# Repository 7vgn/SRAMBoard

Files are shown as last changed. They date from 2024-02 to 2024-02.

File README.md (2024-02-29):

# SRAM Board evolved
## An Add-On for the ATmega644(A) Evaluation Board

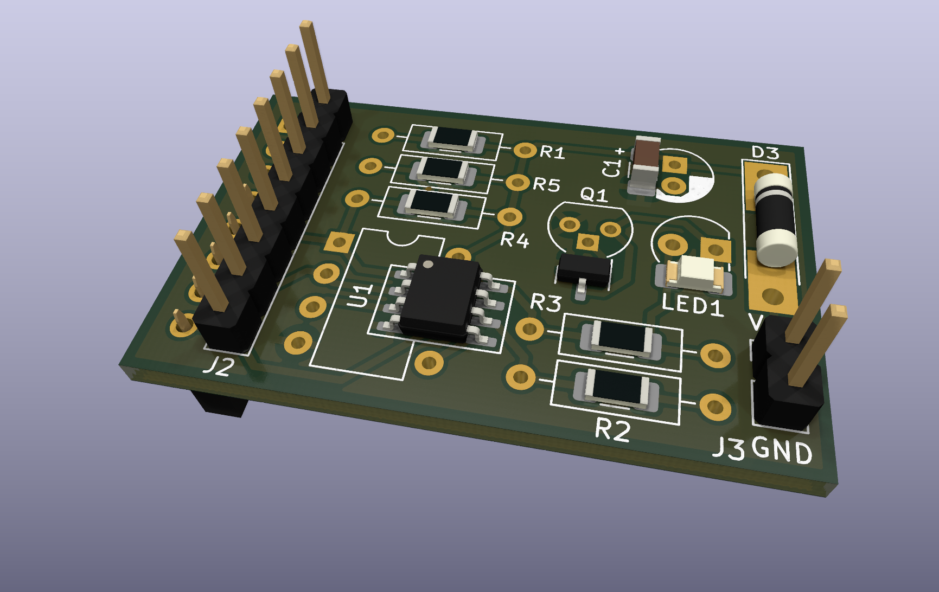
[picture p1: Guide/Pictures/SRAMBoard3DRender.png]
3D render of the add-on board


This is an add-on for the [EvaBoard evolved](https://github.com/7vgn/EvaBoard/) ATmega644(A) evaluation board. It is inspired by (and compatible with) the [add-on board](https://www.embedded.rwth-aachen.de/doku.php?id=lehre:atmegaevaboard) used in the lab course "Praktikum Systemprogrammierung" in the computer science curriculum at RWTH Aachen. It can be used both with the original evaluation board and its remake. 

This repository contains:

- A richly illustrated [Guide Book](Guide/SRAMBoardGuide.pdf) with everything you need to know to build and use the board
- A [KiCAD project](KiCAD/) with the [Schematic](KiCAD/Schematic.pdf) and a PCB layout, ready to be manufactured
- The [bill of materials](BOM/BOM.pdf)
- [Test code](Tests/) for testing and debugging the board

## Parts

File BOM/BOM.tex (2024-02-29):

\documentclass{article}
\usepackage[a4paper, landscape, margin=2.5cm]{geometry}
\usepackage{multirow}
\usepackage{longtable}
\usepackage{textgreek}
\usepackage{hyperref}

\setlength\parindent{0pt}

\begin{document}
\pagestyle{empty}
\section*{SRAM Board evolved -- Bill of Materials}
There is a through-hole and an SMD option for each component. You can mix and match. 
The table below lists the codes for ordering from \href{https://reichelt.de/}{Reichelt}. 
~\\

\begin{center}
\begin{tabular}{|l|l|l|l|l|}
\hline
\textbf{Reference}&\textbf{Part}&\textbf{Quantity}&\textbf{Reichelt\# (THT)}&\textbf{Reichelt\# (SMD)}\cr\hline
C1&Capacitor 100 \textmu F&1&TANTAL 100/6,3&X5R-G1206 100/6\cr\hline
D3&Diode 1N4004&1&1N 4004&1N 4004 SMD\cr\hline
J1&Pin Socket (female) 2.54mm&1&\multicolumn{2}{|l|}{MPE 094-1-008}\cr\hline
J2, J3&Pin Header (male) 2.54mm&1&\multicolumn{2}{|l|}{SL 1X36G 2,54}\cr\hline
LED1&LED (red)&1&LED 3MM RT&KBT KP-3216EC\cr\hline
Q1&NPN Transistor&1&BC 337-25&BC 817-25 SMD\cr\hline
R1, R5&Resistor 1k\textOmega&2&METALL 1,00K&SMD 1/4W 1,0K\cr\hline
R2, R4&Resistor 10k\textOmega&2&METALL 10,0K&SMD 1/4W 10K\cr\hline
R3&Resistor 470\textOmega&1&METALL 470&SMD 1/4W 470\cr\hline
\multirow{2}{*}{U1}&SRAM IC 23LC1024&1&\multicolumn{2}{|l|}{see Guide Book}\cr\cline{2-5}
&Socket&1&GS 8P&--\cr\hline
\end{tabular}
\end{center}

\end{document}

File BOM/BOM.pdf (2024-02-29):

## SRAM Board evolved – Bill of Materials

There is a through-hole and an SMD option for each component. You can mix and match. The table below lists the codes for ordering from Reichelt. (https://reichelt.de/)

Reference | Part | Quantity | Reichelt# (THT) | Reichelt# (SMD)
C1 | Capacitor 100 µF | 1 | TANTAL 100/6,3 | X5R-G1206 100/6
D3 | Diode 1N4004 | 1 | 1N 4004 | 1N 4004 SMD
J1 | Pin Socket (female) 2.54mm | 1 | MPE 094-1-008
J2, J3 | Pin Header (male) 2.54mm | 1 | SL 1X36G 2,54
LED1 | LED (red) | 1 | LED 3MM RT | KBT KP-3216EC
Q1 | NPN Transistor | 1 | BC 337-25 | BC 817-25 SMD
R1, R5 | Resistor 1kΩ | 2 | METALL 1,00K | SMD 1/4W 1,0K
R2, R4 | Resistor 10kΩ | 2 | METALL 10,0K | SMD 1/4W 10K
R3 | Resistor 470Ω | 1 | METALL 470 | SMD 1/4W 470
U1 | SRAM IC 23LC1024 | 1 | see Guide Book
| Socket | 1 | GS 8P | –

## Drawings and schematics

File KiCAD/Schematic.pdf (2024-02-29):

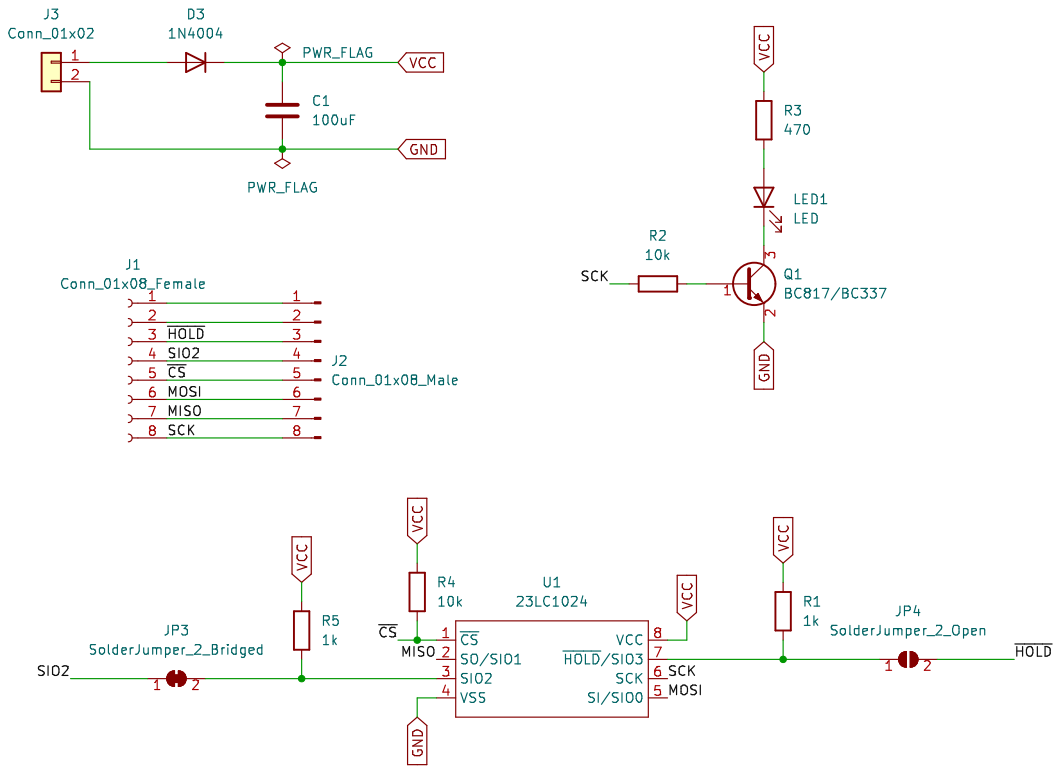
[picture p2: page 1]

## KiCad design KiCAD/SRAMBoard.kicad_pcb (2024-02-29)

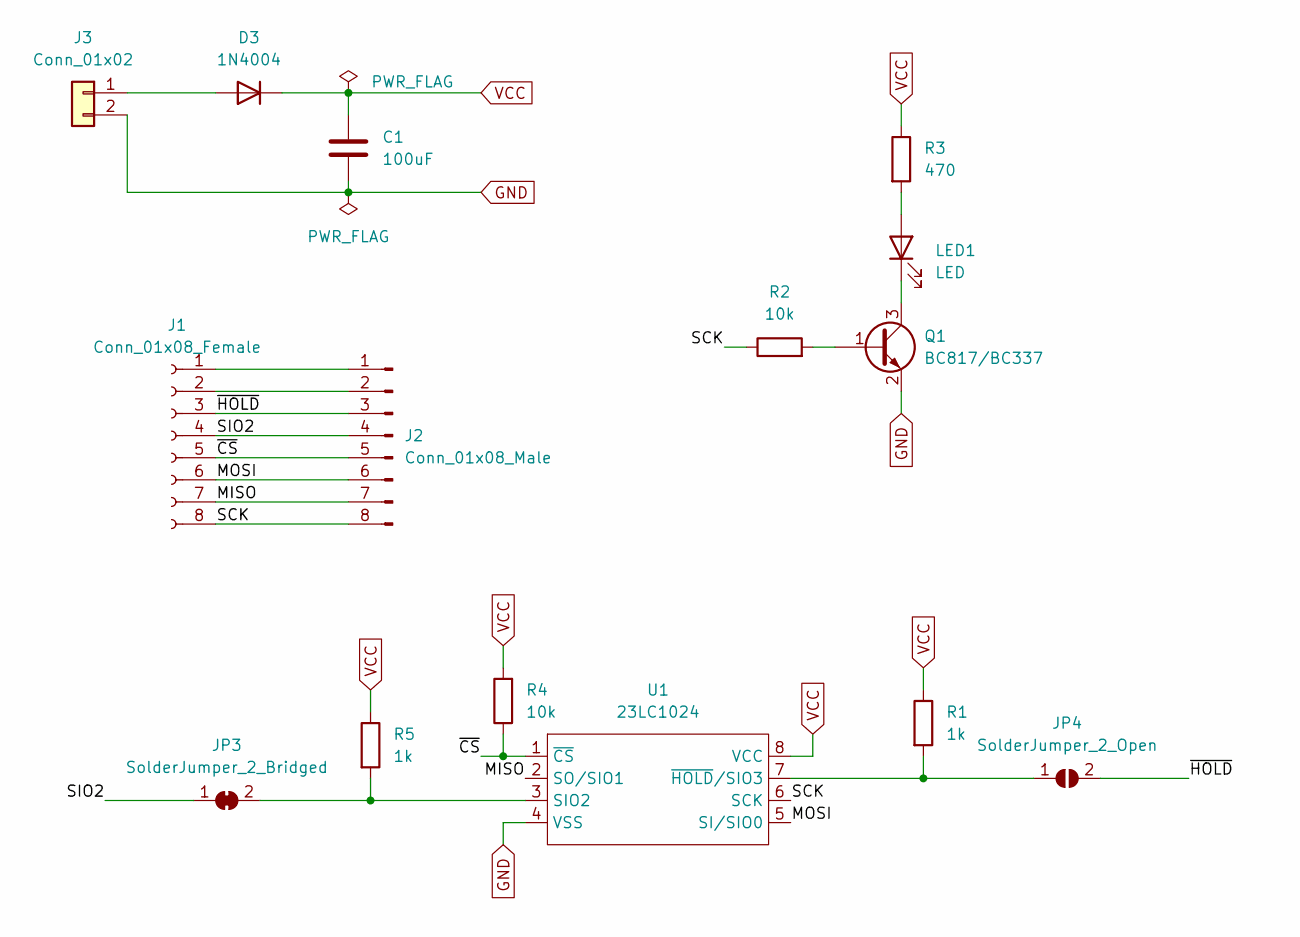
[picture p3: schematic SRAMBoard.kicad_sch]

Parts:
C1: 100uF; C_THT10.16mm_SMD1206
D3: 1N4004; D_MELF-RM10_Universal_Handsoldering
J1: Conn_01x08_Female; PinSocket_1x08_P2.54mm_Vertical
J2: Conn_01x08_Male; PinHeader_1x08_P2.54mm_Vertical
J3: Conn_01x02; PinHeader_1x02_P2.54mm_Vertical
JP3: SolderJumper_2_Bridged; SolderJumper-2_P1.3mm_Bridged_RoundedPad1.0x1.5mm
JP4: SolderJumper_2_Open; SolderJumper-2_P1.3mm_Open_RoundedPad1.0x1.5mm
LED1: LED; LED_THT3mm_SMD1206
Q1: BC817/BC337; Q_SOT23_TO92
R1, R5: 1k; R_THT10.16mm_SMD1206
R2, R4: 10k; R_THT10.16mm_SMD1206
R3: 470; R_THT10.16mm_SMD1206
U1: 23LC1024; DIP_SO_8

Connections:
/MISO: J1.7, J2.7, U1.2 (SO/SIO1)
/MOSI: J1.6, J2.6, U1.5 (SI/SIO0)
/SCK: J1.8, J2.8, R2.1, U1.6 (SCK)
/SIO2: J1.4, J2.4, JP3.1 (A)
/~CS: J1.5, J2.5, R4.1, U1.1 (~CS)
/~HOLD: J1.3, J2.3, JP4.2 (B)
GND: C1.2, J3.2, Q1.2 (E), U1.4 (VSS)
unnamed: D3.2 (A), J3.1
unnamed: J1.1, J2.1
unnamed: J1.2, J2.2
unnamed: JP3.2 (B), R5.2, U1.3 (SIO2)
unnamed: JP4.1 (A), R1.2, U1.7 (~HOLD/SIO3)
unnamed: LED1.1 (K), Q1.3 (C)
unnamed: LED1.2 (A), R3.2
unnamed: Q1.1 (B), R2.2
VCC: C1.1, D3.1 (K), R1.1, R3.1, R4.2, R5.1, U1.8 (VCC)

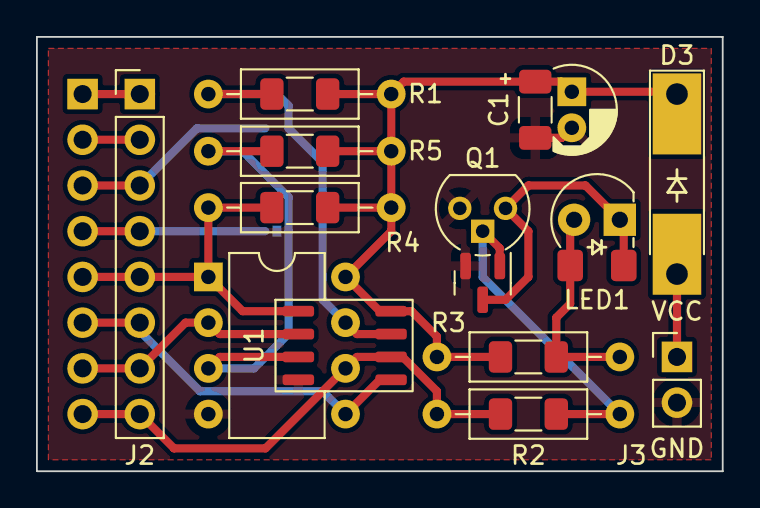
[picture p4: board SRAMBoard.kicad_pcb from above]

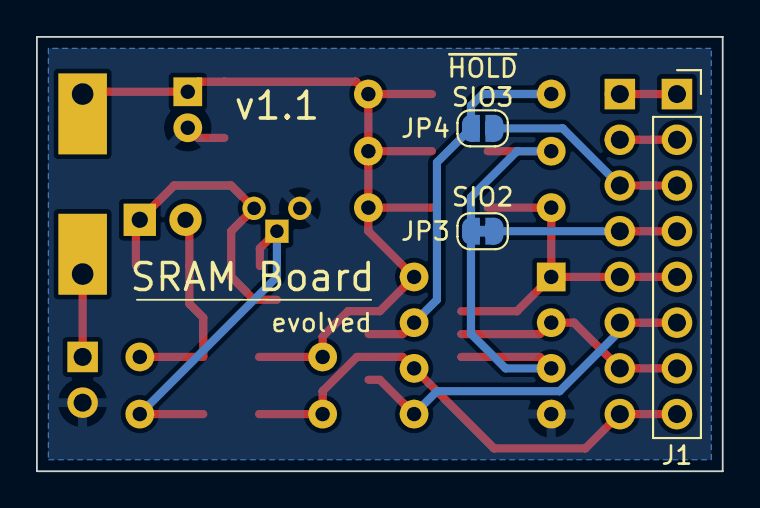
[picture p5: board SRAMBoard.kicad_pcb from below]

Board: 2 copper layers, 38.1 x 24.1 mm, 15 parts (3 on the bottom side), 16 nets.

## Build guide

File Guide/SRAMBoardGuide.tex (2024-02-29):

\documentclass{article}
\usepackage[a4paper]{geometry}
\usepackage[skip=10pt]{parskip}
\usepackage{graphicx}
\usepackage{hyperref}
\usepackage[section]{placeins}
\usepackage[official]{eurosym}
\usepackage{textgreek}
\usepackage{tcolorbox}
\usepackage{listings}
\usepackage{textcomp}
\usepackage{multirow}
\usepackage{tikz}

\setlength\parindent{0pt}

\newenvironment{note}{\begin{tcolorbox}[colback=blue!5!white,colframe=blue!75!black,title=\textbf{Note}]}{\end{tcolorbox}}
\newenvironment{caution}{\begin{tcolorbox}[colback=red!5!white,colframe=red!75!black,title=\textbf{Caution}]}{\end{tcolorbox}}
\newcommand{\evaboard}{\href{https://github.com/7vgn/EvaBoard/}{evaluation board}}
\newcommand{\datasheet}{\href{https://ww1.microchip.com/downloads/aemDocuments/documents/MPD/ProductDocuments/DataSheets/23A102423LC1024-1-Mbit-SPI-Serial-SRAM-with-SDI-SQI-Interface-20005142.pdf}{datasheet}}
\newcommand{\CS}{$\overline{\mbox{CS}}$}
\renewcommand{\SS}{$\overline{\mbox{SS}}$}
\newcommand{\file}[1]{\texttt{#1}}

\lstset
{
	basicstyle=\footnotesize\ttfamily,
	breaklines=true,
	keywordstyle=\bfseries\color{green!40!black},
	commentstyle=\itshape\color{purple!40!black},
	identifierstyle=\color{blue},
	stringstyle=\color{orange},
	tabsize=4
}

\begin{document}
\hypersetup{pageanchor=false}
\begin{titlepage}
\thispagestyle{empty}
\centering
\textsf{\Huge Guide Book}\\[1cm]
\textsf{\Large For the SRAM Add-On Board}\\[3cm]

\end{titlepage}
\hypersetup{pageanchor=true}

\tableofcontents
\section{Introduction}
This is an add-on for the ATmega644(A) \evaboard. It is inspired by (and compatible with) the \href{https://www.embedded.rwth-aachen.de/doku.php?id=lehre:atmegaevaboard}{add-on board} used in the lab course "Praktikum Systemprogrammierung" in the computer science curriculum at RWTH Aachen. 

The university encourages students and educators to build the boards themselves. However, the resources it provides are not always the most comprehensive. 

This project provides a complete remake of the original board with a focus on hand-solderable components. It also includes a ton of documentation, especially for students who have not worked with electronics before. 

\begin{note}
Before reading this, you should familiarize yourself with the \evaboard. Many things written there apply here as well and this document can only be considered complete in conjunction with the \href{https://github.com/7vgn/EvaBoard/Guide/EvaBoardGuide.pdf}{evaluation board's Guide Book}.
\end{note}

\subsection{Getting to Know the Add-On Board}\label{sec:boardOverview}
This add-on board features the \href{https://www.microchip.com/en-us/product/23lc1024}{23LC1024 128kByte Static RAM} by Microchip. See Figure \ref{fig:schematic} for the \href{../KiCAD/Schematic.pdf}{schematic}. 
\begin{figure}[htb]
\centering
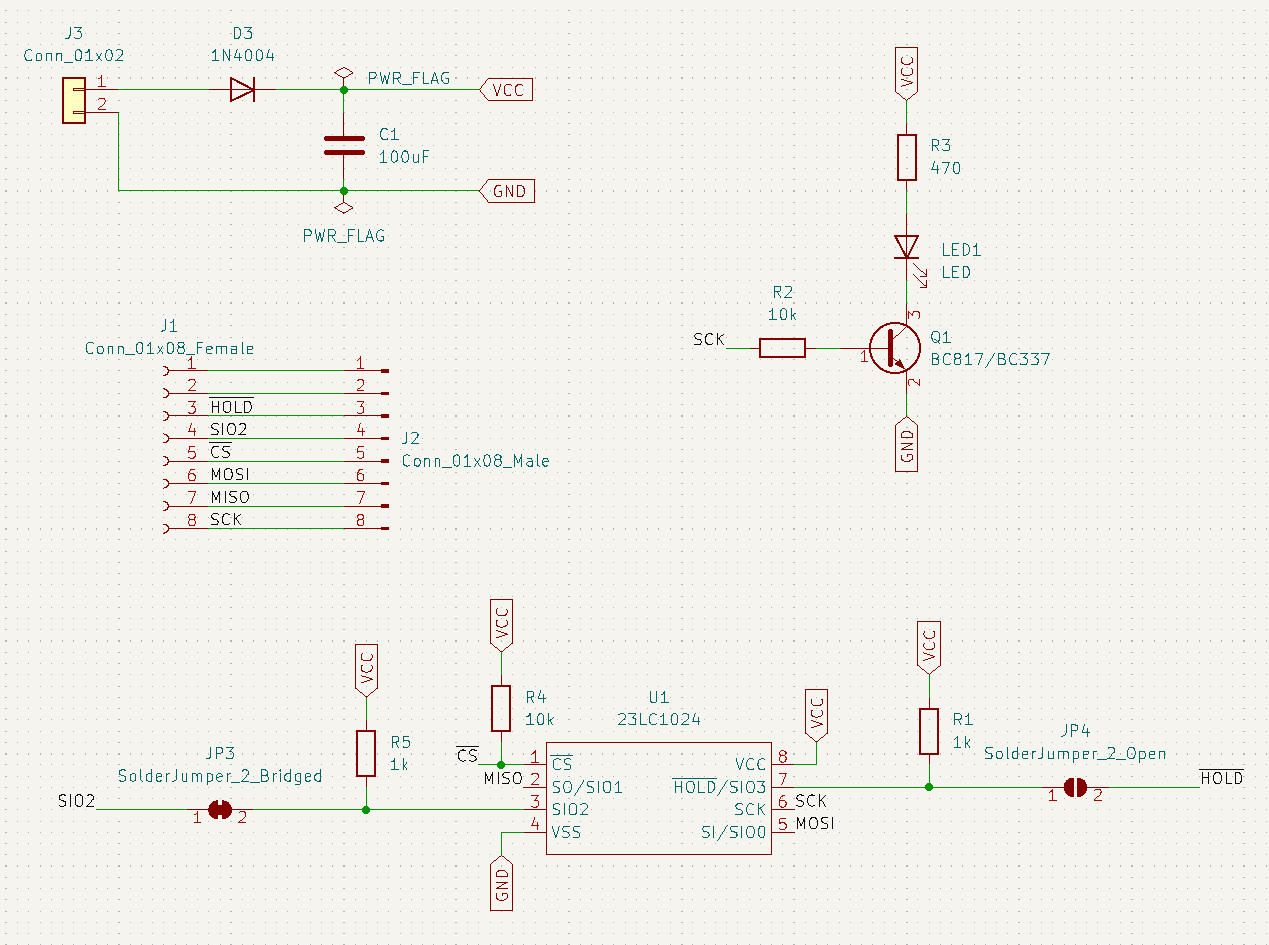
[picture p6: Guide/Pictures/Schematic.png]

\caption{Schematic of the Board}
\label{fig:schematic}
\end{figure}

The 23LC1024 has an SPI interface (among others). When plugged onto Port B (J12) of the evaluation board, the pins match exactly the SPI pins of the ATmega. In addition to that, the add-on board needs power via J3 which can be obtained from the evaluation board's J3 or J4. LED1 signals activity on the SCK line. 

Table \ref{tab:connections} shows the connections between the ATmega and the 23LC1024 when the add-on board is plugged into the Port B connector of the evaluation board (facing towards the side with the LEDs). Port B4 happens to be the $\overline{\mbox{SS}}$ pin, but this is a coincidence -- this pin is not controlled by the ATmega's SPI module while in master mode. 
\begin{table}
\centering
\begin{tabular}{l|l|l|l|l}
\multicolumn{2}{l|}{\textbf{ATmega644}}&\multicolumn{2}{|l|}{\textbf{23LC1024}}&\multirow{2}{*}{\textbf{Remarks}}\cr\cline{1-4}
\textbf{Pin Name}&\textbf{Function}&\textbf{Pin Number}&\textbf{Pin Name}\cr\hline
Port B0&GPIO&\multicolumn{2}{|c|}{--}&\cr\hline
Port B1&GPIO&\multicolumn{2}{|c|}{--}&\cr\hline
Port B2&GPIO&7&$\overline{\mbox{HOLD}}$/SIO3&Only if JP4 is bridged\cr\hline
Port B3&GPIO&3&SIO2&Only if JP3 remains bridged\cr\hline
Port B4&GPIO&1&\CS&\cr\hline
Port B5&MOSI&5&SI/SIO0&\cr\hline
Port B6&MISO&2&MISO/SIO1&\cr\hline
Port B7&SCK&6&SCK&\cr\hline
\end{tabular}
\caption{Connections between the Add-On Board and the Evaluation Board}
\label{tab:connections}
\end{table}

All pins of Port B are passed through to J2. This way, unused pins and pins that can be shared remain usable. 
Port B0 and B1 are not used at all. Port B2 is used only if the solder jumper JP4 is bridged. Port B3 is only used while the the solder jumper JP3 remains bridged\footnote{JP4 is open and JP3 is closed by default. This is because the orginal board comes in this configuration.}. The SPI pins (Port B5..B7) can be shared with other SPI devices so long as separate pins are used for their \CS. 
\FloatBarrier

\subsection{Changes from the Original Board}\label{sec:differences}
\begin{itemize}
\item The main difference is that this board supports both through-hole (THT) and surface mounted (SMD) components. Both kinds are listed in the \href{../BOM/BOM.pdf}{BOM}. You can mix THT and SMD components. See Figure \ref{fig:thtSmd} for a comparison of the different components. \\
The components had to be moved around quite a bit but the connectors J1 and J2 kept their positions. The board is still fully compatible with the original. 
\item The pass-through header J2 was added so that unused or sharable pins of Port B are available for other applications. In particular, you can add multiple devices on the SPI bus of the ATmega. 
\item The pull-up resistor R4 has been added to the \CS{} line. This prevents the 23LC1024 from being accidentally selected while the ATmega is programmed (and leaves Pin B4 floating). 
\item The solder jumper JP3 was added to disconnect Port B3 from SIO2. This line is only required in SQI mode which the ATmega does not support anyway. You can cut it, thus gaining an additional free microcontroller pin. 
\end{itemize}

\begin{figure}[htb]
\centering
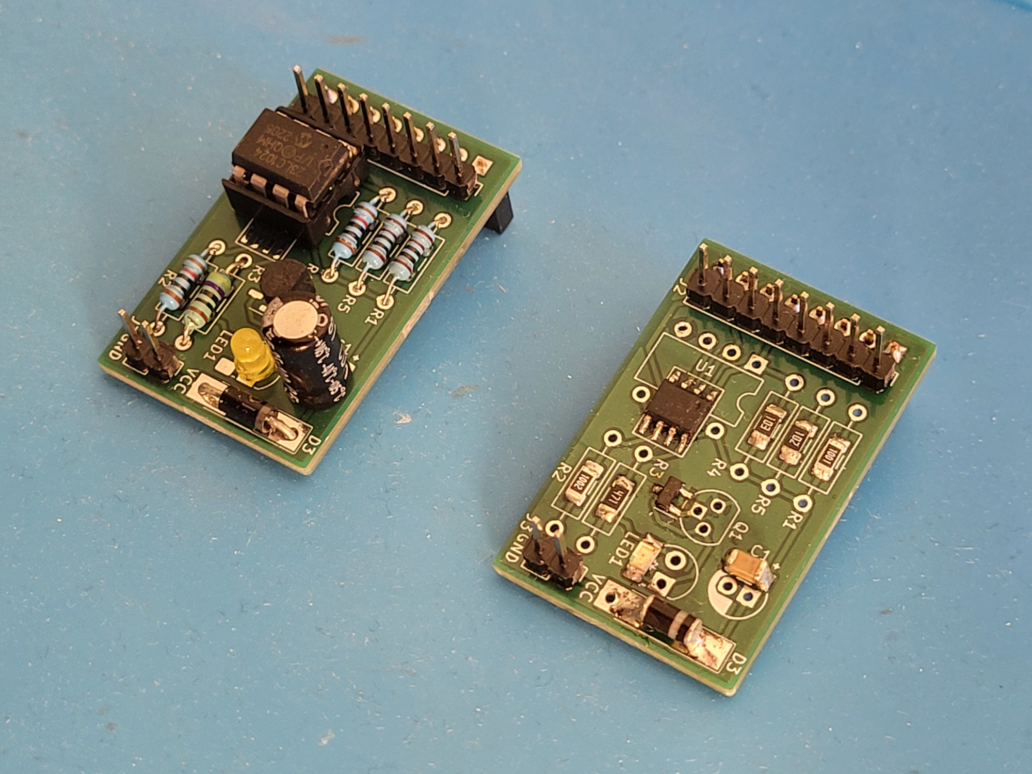
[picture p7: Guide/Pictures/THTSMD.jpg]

\caption{Board with THT components (left) vs. SMD components (right)}
\label{fig:thtSmd}
\end{figure}

\section{Building the Board}
Everything written in the evaluation board's \href{https://github.com/7vgn/EvaBoard/Guide/EvaBoardGuide.pdf}{guide book} applies here as well. This chapter only provides additional information specific to the SRAM add-on board. 

\subsection{Sourcing the 23LC1024}
The 23LC1024 SRAM IC is not easily sourceable in small quantities. Neither Reichelt nor Conrad have it available, and even on marketplaces like eBay or Aliexpress it can be hard to find. You can of course get it from big distributors like Mouser but that comes with disproportionate shipping costs.

Here are some options to look out for:
\begin{itemize}
\item The SMD variant (sometimes named “23LCBT”) seems to have slightly better availability. This PCB supports both DIP and SO-8 (SOIC) packages, but the latter is harder to solder for beginners. 
\item Check for both the normal (-I) and the extended temperature range (-E) variant. While in theory -E should be more expensive, availablity and prices fluctuate.
\item If you don’t need the full 1024 kbit, you can use the 512 kbit version which is pin compatible. The 23LC512 is even available from Reichelt (as SOIC only).
Keep in mind however that you will have to make a slight change to your firmware since the 23LC512 uses 2 rather than 3 address bytes.
\end{itemize}

\begin{caution}
Do not buy the 23\emph{A}1024. It is not 5V-tolerant. 
\end{caution}

\begin{note}
There is an even smaller SMD variant (TSSOP) which the PCB \emph{cannot} accommodate. You might be able to use an SSOP-to-DIP adapter (``breakout board''). However, SSOP is \emph{very hard} to solder by hand -- there is less than half a millimetre of space between adjacent legs. 
\end{note}

\subsection{Soldering SMD Components}
\begin{note}
If you are using through-hole (THT) components, this section is not relevant to you. 
\end{note}

SMD components are somewhat harder to solder due to their size. This board uses the largest SMD components available, but they are still much smaller than their THT counterparts. 

In addition to the standard tools, you need some tweezers (ideally cross-locking) and -- depending on how good your eyesight is -- a magnifying glass. Using flux\footnote{Flux is quite expensive, but you can make your own: Take an empty nail polish remover bottle and fill it with some rosin (colophony) flakes. Rosin is pretty cheap and if you happen to know a violin player, they might give you the tiny amount necessary for free. Add some isopropyl alcohol and let it sit until the rosin dissolves.} makes things much easier. 

Make sure the PCB is clean; use isopropyl alcohol if necessary. It is important that the PCB's metal pads and the solder mask in between are in good condition. Do not solder for more than a few seconds at a time, otherwise you might destroy them. If you have flux, apply some to all the pads of a component before soldering. 

Start by heating one of the pads of the PCB, then add a tiny bit of solder onto it. Grab the component with tweezers and move it in the correct position. Make sure the orientation is correct. Then heat the prepared pad with your soldering iron, while still firmly holding the component in place. Remove the iron and let it cool for a few seconds. The component is now attached on one side (or with one leg). 

It the placement isn't quite right, grab the component with tweezers, re-heat the solder joint and move or rotate slightly. The solder joint doesn't have to be perfect, it just needs to hold the component in place. Once the component is correctly positioned, solder the remaining sides or legs. After that you can re-do the first solder joint if necessary. 

Use only very small amounts of solder. The components should lie flat on the PCB, not swim on top of a big drop of solder. If necessary, remove solder with a soldering pump or wick. 

If the solder bridges neighbouring pins, use wick to remove it. Adding some more flux can also help. 
Finally, clean the PCB with isopropyl alcohol to remove flux residue. 

With SMD components it is even more important to check the connections using a multimeter in continuity testing mode. At the very least verify that the pins of the IC are connected to the corresponding pins of J1 and J3 and that there is no short between neighbouring pins. 

\section{Testing}
The test programs can be found in the \href{../Tests/}{\file{Tests/} subdirectory} of this repository. They all come with makefiles for AVR-GCC and AVRDUDE. Alternatively, you can create a project in your IDE of choice and import the source files there. Be sure to define the \lstinline[language=C]{F_CPU} constant if your IDE doesn't do that automatically.

\subsection{Bit-Banging}\label{sec:bitBang}
The code for this test can be found in \href{../Tests/BitBang/}{\file{Tests/BitBang/}}. 

This test uses a technique called \href{https://en.wikipedia.org/wiki/Bit_banging}{``bit-banging''} to communicate with the SRAM. This means, rather than using the ATmega's SPI peripheral, it generates the required bit sequence on the pins in software. This approach is much slower but it allows for a free choice of the pins: You can attach the add-on board to any port, so long as you change the configuration in \texttt{main.c} accordingly. 

The program uses a pseudo random number generator to choose a 17-bit address and two bytes of data. It then writes the data to the SRAM at that address and tries to read it back again. This is repeated forever or until a discrepancy is found. 

\paragraph{Preparation}
Plug the SRAM board onto Port B (J12) facing towards the side with the LEDs and provide it with power from connector J3 or J4 of the evaluation board. Connect the LCD (J15) to Port A (J11), i.e.\ connect R/W to Port A6, EN to Port A5, RS to Port A4, DB7 to Port A3, DB6 to Port A2, DB5 to Port A1, and DB4 to Port A0. See Figure \ref{fig:bitBang}. 

\begin{figure}[htb]
\centering
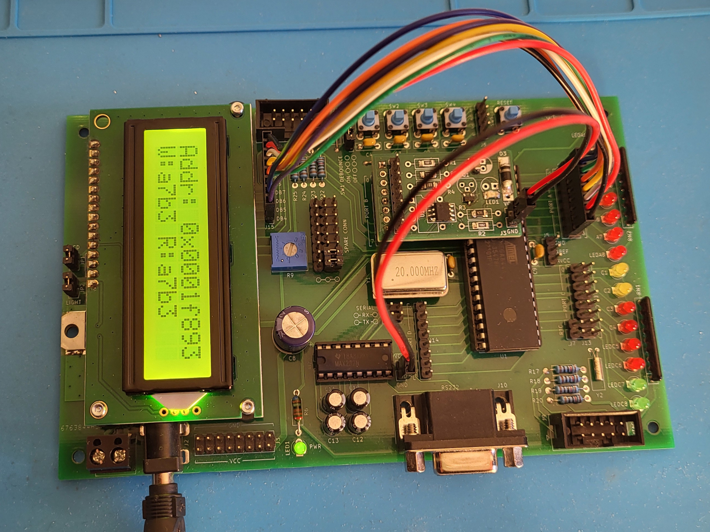
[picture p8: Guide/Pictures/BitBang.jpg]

\caption{Setup for the Bit-Banging Test}
\label{fig:bitBang}
\end{figure}

\paragraph{Expected Result}
The LCD should output the currently used address and the data it writes and reads. It should never show ``E'' at the end of the second row. 

\paragraph{Troubleshooting}
Make sure the evaluation board, including the LCD, is working reliably. Re-check all connections. Is the add-on board powered with the correct polarity? 

If all connections are correct and it still doesn't work, then there is either a bad solder joint or the SRAM IC is defective. The LED should flash whenever the SCK line is high, i.e.\ when there's activity on the SPI bus. If it doesn't, there might be a problem with the SCK line. Reading a value of 0xffff indicates that the SRAM is not sending data (the pull-up on Port B6 causes the controller to read ones). This could be because of a problem on the MISO line (but also on the MOSI line, since it is hard to tell whether the SRAM even receives any commands). 

\subsection{Manually Communicating over SPI}
This is not so much a test as it is an opportunity to learn about the SPI protocol. While SPI devices have upper speed limits (see Table 1-2 in the \datasheet), they don't usually have lower limits, meaning you can communicate with them as slowly as you like. So why not try and do it by hand. 

In theory, we could remove the microcontroller altogether and just wire some buttons to the SRAM board. In practice, it would be incredibly tedious to hold and release buttons without slipping up or miscounting. So we're doing it manually but with the help of the microcontroller. 

\paragraph{Preparation}
Set up the LCD and the add-on board just like in the previous test. Add three wires from Pins C0, C1, and C6 to SW1, SW2, and SW3. Compile and program the code from the \href{../Tests/Manual/}{\file{Tests/Manual/} subdirectory}. 

\begin{figure}[htb]
\centering
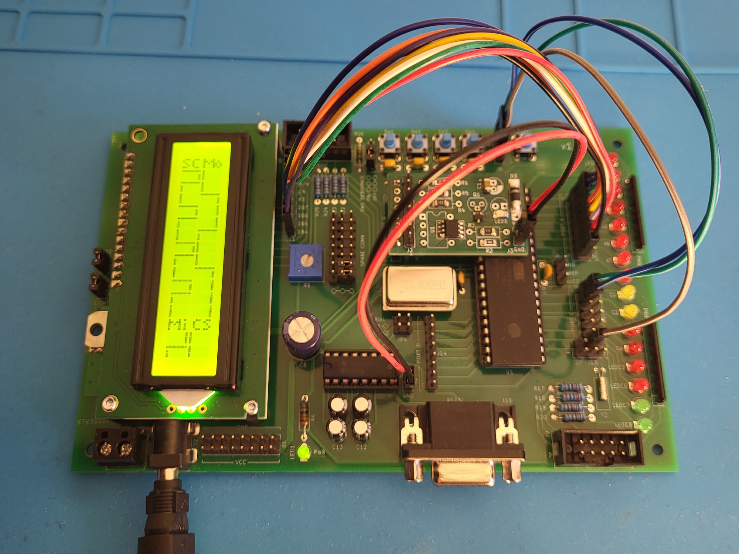
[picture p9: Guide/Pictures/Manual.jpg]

\caption{Setup for the Manual Test}
\label{fig:manual}
\end{figure}

\paragraph{Expected Result}
Each press of a button flips the corresponding line from high to low or vice versa. SW1 is for MOSI, SW2 for SCK, and SW3 for \CS. The LCD shows a diagram for each of these lines and MISO. 

Figure \ref{fig:spiManualSequence} shows the RDMR sequence (0x05 0x00, see Section 2.5 of the \datasheet{}), which is a short example you can do manually. It also depicts the expected response on MISO (0x40). Read and write instructions are also possible but as they are at least 40 bits long, they require more patience. 

\begin{figure}[htb]
\centering
\begin{tikzpicture}[scale=0.6]
\coordinate (CS) at (0,7);
\coordinate (MOSI) at (0,5);
\coordinate (SCK) at (0,3);
\coordinate (MISO) at (0,0);
% CS
\node[anchor=east] at (CS) {\CS};
\draw (CS) ++ (0.5,0.5) -- ++(0.5,0) -- ++(0.1,-1) -- ++(20.5,0) -- ++(0.1,1) -- ++(0.5,0);
% MOSI
\node[anchor=east] at (MOSI) {MOSI};
\draw (MOSI) ++ (0.5,-0.5) -- ++(6.8,0)
-- ++(0.1,1) -- ++(1,0) -- ++(0.1,-1) -- ++(1.2,0)
-- ++(0.1,1) -- ++(1,0) -- ++(0.1,-1) -- ++(11.3,0);
% SCK
\node[anchor=east] at (SCK) {SCK};
\draw (SCK) ++ (0.5,-0.5) -- ++(1,0)
-- ++(0.1,1) -- ++(0.5,0) -- ++(0.1,-1) -- ++(0.5,0)
-- ++(0.1,1) -- ++(0.5,0) -- ++(0.1,-1) -- ++(0.5,0)
-- ++(0.1,1) -- ++(0.5,0) -- ++(0.1,-1) -- ++(0.5,0)
-- ++(0.1,1) -- ++(0.5,0) -- ++(0.1,-1) -- ++(0.5,0)
-- ++(0.1,1) -- ++(0.5,0) -- ++(0.1,-1) -- ++(0.5,0)
-- ++(0.1,1) -- ++(0.5,0) -- ++(0.1,-1) -- ++(0.5,0)
-- ++(0.1,1) -- ++(0.5,0) -- ++(0.1,-1) -- ++(0.5,0)
-- ++(0.1,1) -- ++(0.5,0) -- ++(0.1,-1) -- ++(1,0)
-- ++(0.1,1) -- ++(0.5,0) -- ++(0.1,-1) -- ++(0.5,0)
-- ++(0.1,1) -- ++(0.5,0) -- ++(0.1,-1) -- ++(0.5,0)
-- ++(0.1,1) -- ++(0.5,0) -- ++(0.1,-1) -- ++(0.5,0)
-- ++(0.1,1) -- ++(0.5,0) -- ++(0.1,-1) -- ++(0.5,0)
-- ++(0.1,1) -- ++(0.5,0) -- ++(0.1,-1) -- ++(0.5,0)
-- ++(0.1,1) -- ++(0.5,0) -- ++(0.1,-1) -- ++(0.5,0)
-- ++(0.1,1) -- ++(0.5,0) -- ++(0.1,-1) -- ++(0.5,0)
-- ++(0.1,1) -- ++(0.5,0) -- ++(0.1,-1) -- ++(1.5,0);
% MISO
\node[anchor=east] at (MISO) {MISO};
\draw (MISO) ++ (0.5,0.5) -- ++(10,0)
-- ++(0.1,-1) -- ++(1.6,0) -- ++(0.1,1) -- ++(1.1,0)
-- ++(0.1,-1) -- ++(8.1,0) -- ++(0.1,1) -- ++(0.5,0);
\end{tikzpicture}
\caption{Example Sequence for Manual Test}
\label{fig:spiManualSequence}
\end{figure}

\section{Known Issues}
While the diode is great for preventing damage when the supply voltage is plugged in the wrong way, it causes a violation of the VCC+0.3V maximum input voltage on the 23LC1024's signal lines. So far, we have not observed any problems arising from that. 

\section{Version History}
\begin{description}
\item[v1.0] Initial release
\item[v1.1] Added pull-up resistor R4 for \CS{} and moved JP4 to the back to make space for it. Added JP3 so SIO2 can be disconnected. \\
On v1.0 the pull-up resistor for \CS{} can be soldered to the back, see Figure \ref{fig:csPullupV10}. 
\end{description}

\begin{figure}[htb]
\centering
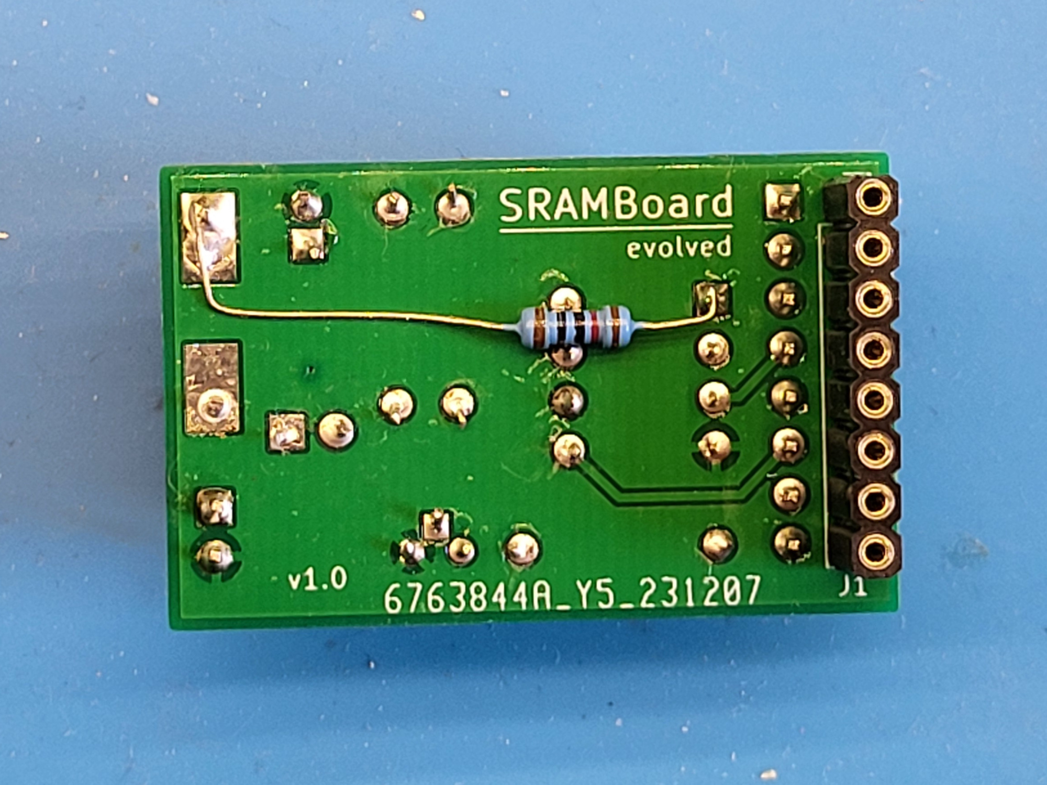
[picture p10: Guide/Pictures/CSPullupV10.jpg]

\caption{Adding a Pull-up Resistor for \CS{} on v1.0}
\label{fig:csPullupV10}
\end{figure}

\end{document}

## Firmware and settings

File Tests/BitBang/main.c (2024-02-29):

/*
 * Testing the SRAMBoard add-on for the Evaluation Board
 *
 * Plug the SRAMBoard onto Port B (J12) facing towards the side with the LEDs
 * and provide it with power from J3 or J4. 
 * Connect the LCD (J15) to Port A (J11), i.e. connect R/W to Port A6, EN to
 * Port A5, RS to Port A4, DB7 to Port A3, DB6 to Port A2, DB5 to Port A1,
 * and DB4 to Port A0. 
 * 
 * This is a very slow bit-banging implementation. The ATmega's SPI peripheral
 * is not used. 
 */

#include<avr/io.h>
#include<util/delay.h>
#include<stdlib.h>
#include"lcd.h"

//=============================================================================
// Configuration

// All pins can be chosen individually. Default settings are for Port B and
// coincide with the SPI peripheral pins. 

#define MOSI_REG_DDR DDRB
#define MOSI_REG_PORT PORTB
#define MOSI_PIN 5

#define MISO_REG_DDR DDRB
#define MISO_REG_PORT PORTB
#define MISO_REG_PIN PINB
#define MISO_PIN 6

#define SCK_REG_DDR DDRB
#define SCK_REG_PORT PORTB
#define SCK_PIN 7

#define CS_REG_DDR DDRB
#define CS_REG_PORT PORTB
#define CS_PIN 4

//=============================================================================
// SPI helper functions

void spiInit()
{
	// Configure CS as output, high
	CS_REG_PORT &= ~(1 << CS_PIN);
	CS_REG_DDR |= (1 << CS_PIN);

	// Configure MOSI and SCK as output, low
	MOSI_REG_PORT &= ~(1 << MOSI_PIN);
	MOSI_REG_DDR |= (1 << MOSI_PIN);
	SCK_REG_PORT &= ~(1 << SCK_PIN);
	SCK_REG_DDR |= (1 << SCK_PIN);

	// Configure MISO as input with no pull-up
	MISO_REG_PORT &= ~(1 << MISO_PIN);
	MISO_REG_DDR &= ~(1 << MISO_PIN);
}

void spiStart()
{
	// Pull CS low to select the chip
	CS_REG_PORT &= ~(1 << CS_PIN);
	_delay_us(10);
}

void spiStop()
{
	// Drive CS (PB4) high to deselect the chip
	CS_REG_PORT |= (1 << CS_PIN);
	_delay_us(10);
}

uint8_t spiTransfer(uint8_t data)
{
	for(uint8_t i = 0; i < 8; i++)
	{
		// Output data's MSB on MOSI
		MOSI_REG_PORT = (MOSI_REG_PORT & ~(1 << MOSI_PIN)) | ((data >> 7) << MOSI_PIN);
		_delay_us(10);
		// Drive SCK high
		SCK_REG_PORT |= (1 << SCK_PIN);
		_delay_us(10);
		// Read bit from MISO and shift it into data from the left
		data = (data << 1) | ((MISO_REG_PIN >> MISO_PIN) & 1);
		// Pull SCK low again
		SCK_REG_PORT &= ~(1 << SCK_PIN);
		_delay_us(10);
	}
	return data;
}

//=============================================================================
// Main function

void main(void)
{
	// Initialise LCD
	lcd_init();
	lcd_writeString("Initialising...");

	// Initialise SPI
	spiInit();
	_delay_ms(500);

	// Set sequential mode (supposed to be default according to datasheet but isn't)
	spiStart();
	spiTransfer(0x01);
	spiTransfer(0x40);
	spiStop();

	// Do some reading and writing
	while(1)
	{
		// Choose an address and data
		uint32_t address = (uint32_t)random() & 0x0001ffff;
		uint16_t dataSend = (uint16_t)random();
		lcd_clear();
		lcd_writeString("Addr: ");
		lcd_write32bitHex(address);
		lcd_line2();

		// Write some data
		lcd_line2();
		lcd_writeString("W:");
		lcd_writeHexWord(dataSend);
		spiStart();
		spiTransfer(0x02);
		spiTransfer((uint8_t)(address >> 16));
		spiTransfer((uint8_t)(address >> 8));
		spiTransfer((uint8_t)address);
		spiTransfer((uint8_t)(dataSend >> 8));
		spiTransfer((uint8_t)dataSend);
		spiStop();

		// Read it back
		spiStart();
		spiTransfer(0x03);
		spiTransfer((uint8_t)(address >> 16));
		spiTransfer((uint8_t)(address >> 8));
		spiTransfer((uint8_t)address);
		uint16_t dataRecv = ((uint16_t)spiTransfer(0xff) << 8) | (uint16_t)spiTransfer(0xff);
		spiStop();
		lcd_goto(2, 8);
		lcd_writeString("R:");
		lcd_writeHexWord(dataRecv);

		// Check
		if(dataRecv != dataSend)
		{
			lcd_goto(2, 16);
			lcd_writeString("E");
			while(1);
		}

		_delay_ms(2000);
	}
}

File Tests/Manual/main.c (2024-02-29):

/*
 * \brief Manually communicate with the 23LC1024 via SPI
 *
 * Plug the SRAMBoard onto Port B (J12) facing towards the side with the LEDs
 * and provide it with power from J3 or J4. 
 * Connect the LCD (J15) to Port A (J11), i.e. connect R/W to Port A6, EN to
 * Port A5, RS to Port A4, DB7 to Port A3, DB6 to Port A2, DB5 to Port A1,
 * and DB4 to Port A0. 
 * Connect the Buttons SW1..3 (J6) to Port C0, C1, and C6 (J13). 
 * Connect an LED (doesn't matter which) to PC7. 
 */

#include<avr/io.h>
#include<util/delay.h>
#include<stdbool.h>
#include"lcd.h"

/**
 * \brief Stores the (recent) history of the SPI lines
 */
typedef struct {uint16_t mosi, sck, cs, miso;} SPI;

/**
 * \brief Displays the history of an SPI pin as a graph 
 */
void showHistory(uint16_t history, uint8_t length)
{
	for(uint8_t i = 0; i < length; i++)
		lcd_writeChar((history >> (length - i - 1)) & 0x03);
}

/**
 * \brief Updates the graphs on the LCD
 */
void updateLcd(SPI history)
{
	// Update LCD
	lcd_goto(1, 2);
	showHistory(history.mosi, 12);
	lcd_goto(2, 2);
	showHistory(history.sck, 12);
	lcd_goto(1, 15);
	showHistory(history.cs, 2);
	lcd_goto(2, 15);
	showHistory(history.miso, 2);
}

/**
 * \brief Retrieves the state of the MISO line and the buttons and stores it in
 * one byte: 0b(0 0 0 0 <MISO> <SW3> <SW2> <SW1>)
 */
inline uint8_t misoBtnState()
{
	return ((PINC >> 4) & 4) | (PINC & 3) | ((PINB >> 3) & 8);
}

/**
 * \brief Checks what changes have happened between two states.
 * For MISO any change counts, for the buttons only falling edges.
 */
inline uint8_t misoBtnChanges(uint8_t oldState, uint8_t newState)
{
	return ((oldState ^ newState) & 8) | ((oldState & ~newState) & 7);
}

/**
 * \brief Main program
 */
void main(void)
{
	// Initialise LCD
	lcd_init();
	lcd_registerCustomChar(0, CUSTOM_CHAR(0x00, 0x00, 0x00, 0x00, 0x00, 0x00, 0x00, 0x1f)); // low
	lcd_registerCustomChar(1, CUSTOM_CHAR(0x17, 0x10, 0x10, 0x10, 0x10, 0x10, 0x10, 0x10)); // rising
	lcd_registerCustomChar(2, CUSTOM_CHAR(0x10, 0x10, 0x10, 0x10, 0x10, 0x10, 0x10, 0x17)); // falling
	lcd_registerCustomChar(3, CUSTOM_CHAR(0x1f, 0x00, 0x00, 0x00, 0x00, 0x00, 0x00, 0x00)); // high
	lcd_registerCustomChar(4, CUSTOM_CHAR(0x06, 0x09, 0x06, 0x1f, 0x08, 0x04, 0x08, 0x1f)); // MOSI
	lcd_registerCustomChar(5, CUSTOM_CHAR(0x00, 0x11, 0x11, 0x0e, 0x00, 0x12, 0x15, 0x09)); // SCK
	lcd_registerCustomChar(6, CUSTOM_CHAR(0x12, 0x15, 0x09, 0x00, 0x11, 0x11, 0x0e, 0x00)); // CS
	lcd_registerCustomChar(7, CUSTOM_CHAR(0x00, 0x17, 0x00, 0x1f, 0x08, 0x04, 0x08, 0x1f)); // MISO
	lcd_writeString("              ");
	lcd_writeString("              ");

	// Initialise SPI pins:
	// MOSI (PB5) and SCK (PB7) as ouput low, CS (PB4) as output high,
	// MISO (PB6) as input without pull-up
	PORTB = 0b00010000;
	DDRB = 0b10110000;

	// Initialise button pins:
	// SW1 (PC0), SW2 (PC1), SW3 (PC6) as inputs with pull-up
	DDRC = 0;
	PORTC = 0b01000011;

	// Store the history of MOSI, MISO, SCK, and CS
	SPI history = {.mosi = 0, .sck = 0, .cs = 0xffff, .miso = (PINB >> 6) & 1 ? 0xffff : 0};
	updateLcd(history);

	// Main loop
	uint8_t state = misoBtnState();
	while(1)
	{
		// Check if a button is pressed or the MISO pin changed
		uint8_t oldState = state;
		state = misoBtnState();
		uint8_t changes = misoBtnChanges(oldState, state);
		if(changes)
		{
			// Update histories
			history.mosi = (history.mosi << 1) | (changes & 1 ? ~history.mosi & 1 : history.mosi & 1);
			history.sck = (history.sck << 1) | (changes & 2 ? ~history.sck & 1 : history.sck & 1);
			history.cs = (history.cs << 1) | (changes & 4 ? ~history.cs & 1 : history.cs & 1);
			history.miso = (history.miso << 1) | ((PINB >> 6) & 1);

			// Update MOSI, SCK, and CS pins
			PORTB = (PORTB & 0b01001111)
			      | ((uint8_t)(history.mosi & 1) << 5)
			      | ((uint8_t)(history.sck & 1) << 7)
			      | ((uint8_t)(history.cs & 1) << 4);

			// Update LCD
			updateLcd(history);
		}
		_delay_ms(10);
	}
}
